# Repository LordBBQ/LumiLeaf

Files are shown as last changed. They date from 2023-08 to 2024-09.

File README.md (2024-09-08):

# LumiLeaf
Smart affordable adressable LED panels

### Assembly
##### Step 1

Remove the printed supports and adhesion materials from the part.

##### Step 2

Use a soldering iron to insert the 4 terminal heatset inserts.


Insert the M3 terminal bolts and washers into the inserts.

##### Step 3


Strip a length of solid core ethernet cable.


Separate the individual strands, and remove the twists as much as possible.

##### Step 4

Route the wires through the wire channel as shown.

##### Step 5

Cut a 250mm length of LED strip.



Adhere this around the edge of the light.

##### Step 6

Carefully solder the 4 wires to the 5V, GND, D+ and D- pins. This is very fiddly, and may require multiple attempts.

##### Step 7

Route the wires out the wire hole, and spread them to each of their terminals. 


Loop each wire around a bolt and tighten, ensuring there is no insulation clamped under the screw.

##### Step 8

Use a multimeter to check check for short circuts in the assembly.

##### Step 9

Cut out a triangular section of foil to act as the reflector.



Use a thin double sided tape to adhere the foil over the back panel.

>[!WARNING]
>Ensure the foil does not make contact with the LED strip or exposed wire. This could lead to a short circut!

##### Step 10
Repeat for all other desired modules. Attach the lasercut or 3D printed diffuser and bezel.

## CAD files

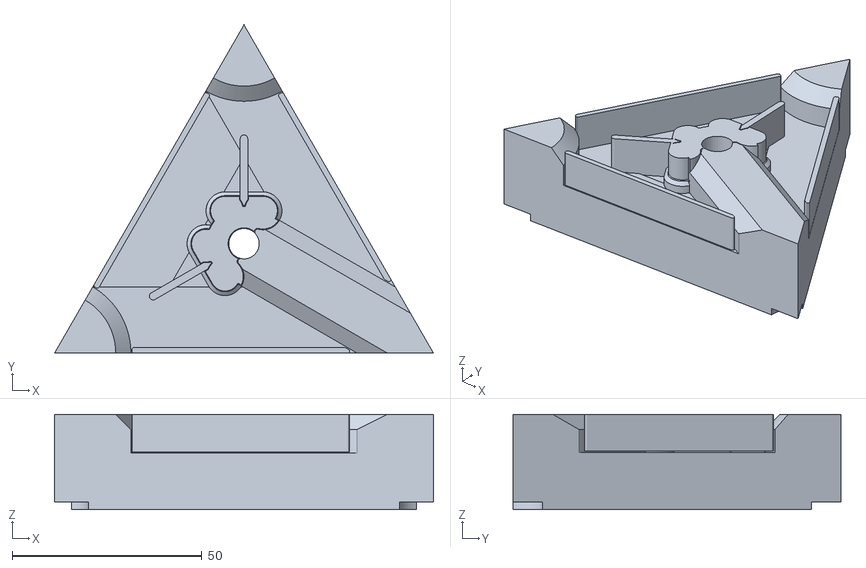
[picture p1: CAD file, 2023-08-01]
STLs/ElementBodyV2.stl
99.8 x 86.5 x 25.1

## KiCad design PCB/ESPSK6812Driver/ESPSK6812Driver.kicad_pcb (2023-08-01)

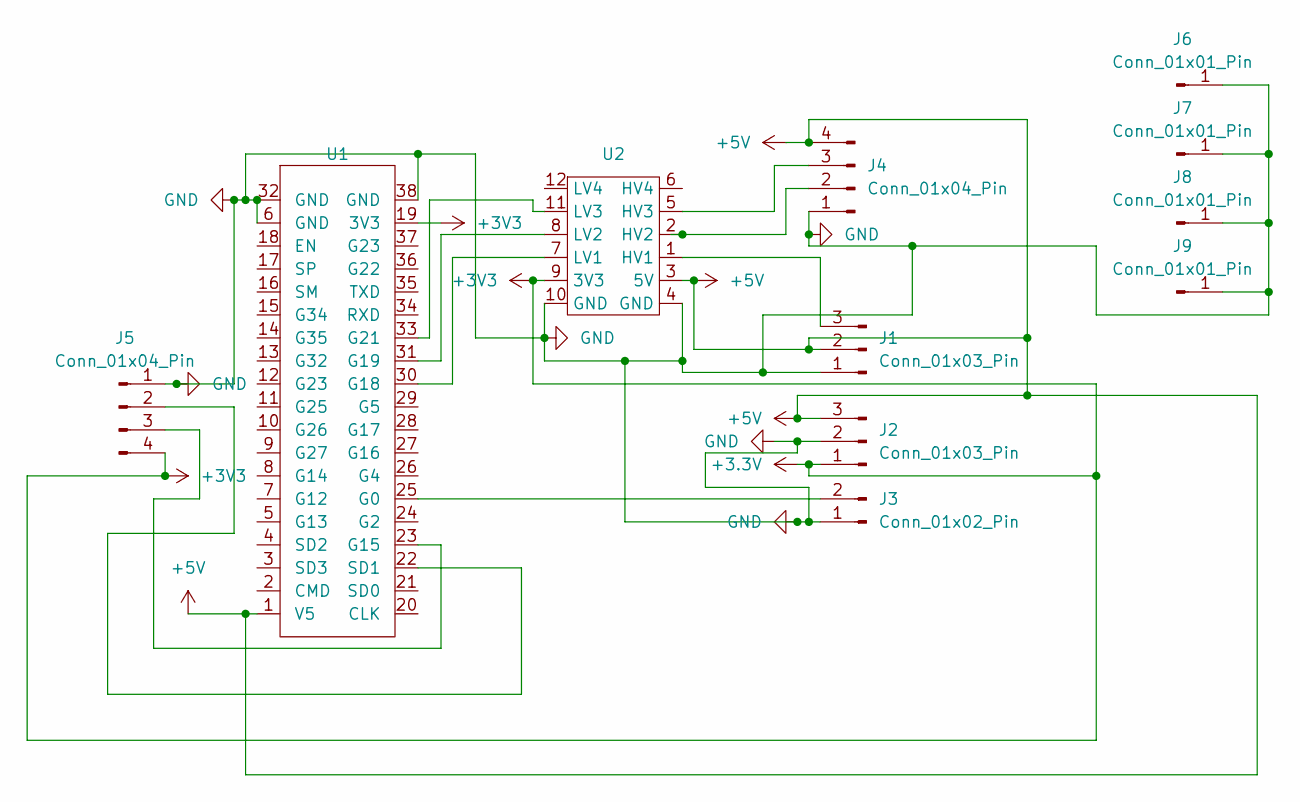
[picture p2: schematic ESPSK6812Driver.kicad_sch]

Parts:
J1, J2: Conn_01x03_Pin; JST_XH_B3B-XH-AM_1x03_P2.50mm_Vertical
J3: Conn_01x02_Pin; JST_XH_B2B-XH-AM_1x02_P2.50mm_Vertical
J4, J5: Conn_01x04_Pin; PinHeader_1x04_P2.54mm_Vertical
J6, J7, J8, J9: Conn_01x01_Pin; MountingHole_3.2mm_M3_DIN965_Pad
U1: ESPModuleJaycar
U2: LogicLevelShifterBidirectional

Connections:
+3.3V: J2.1, J5.4, U1.19 (3V3), U2.9 (3V3)
+5V: J1.2, J2.3, J4.4, U1.1 (V5), U2.3 (5V)
GND: J1.1, J2.2, J3.1, J4.1, J5.1, J6.1, J7.1, J8.1, J9.1, U1.6 (GND), U1.32 (GND), U1.38 (GND), U2.4 (GND), U2.10 (GND)
unnamed: J1.3, U2.1 (HV1)
unnamed: J3.2, U1.25 (G0)
unnamed: J4.2, U2.2 (HV2)
unnamed: J4.3, U2.5 (HV3)
unnamed: J5.2, U1.22 (SD1)
unnamed: J5.3, U1.23 (G15)
unnamed: U1.30 (G18), U2.7 (LV1)
unnamed: U1.31 (G19), U2.8 (LV2)
unnamed: U1.33 (G21), U2.11 (LV3)

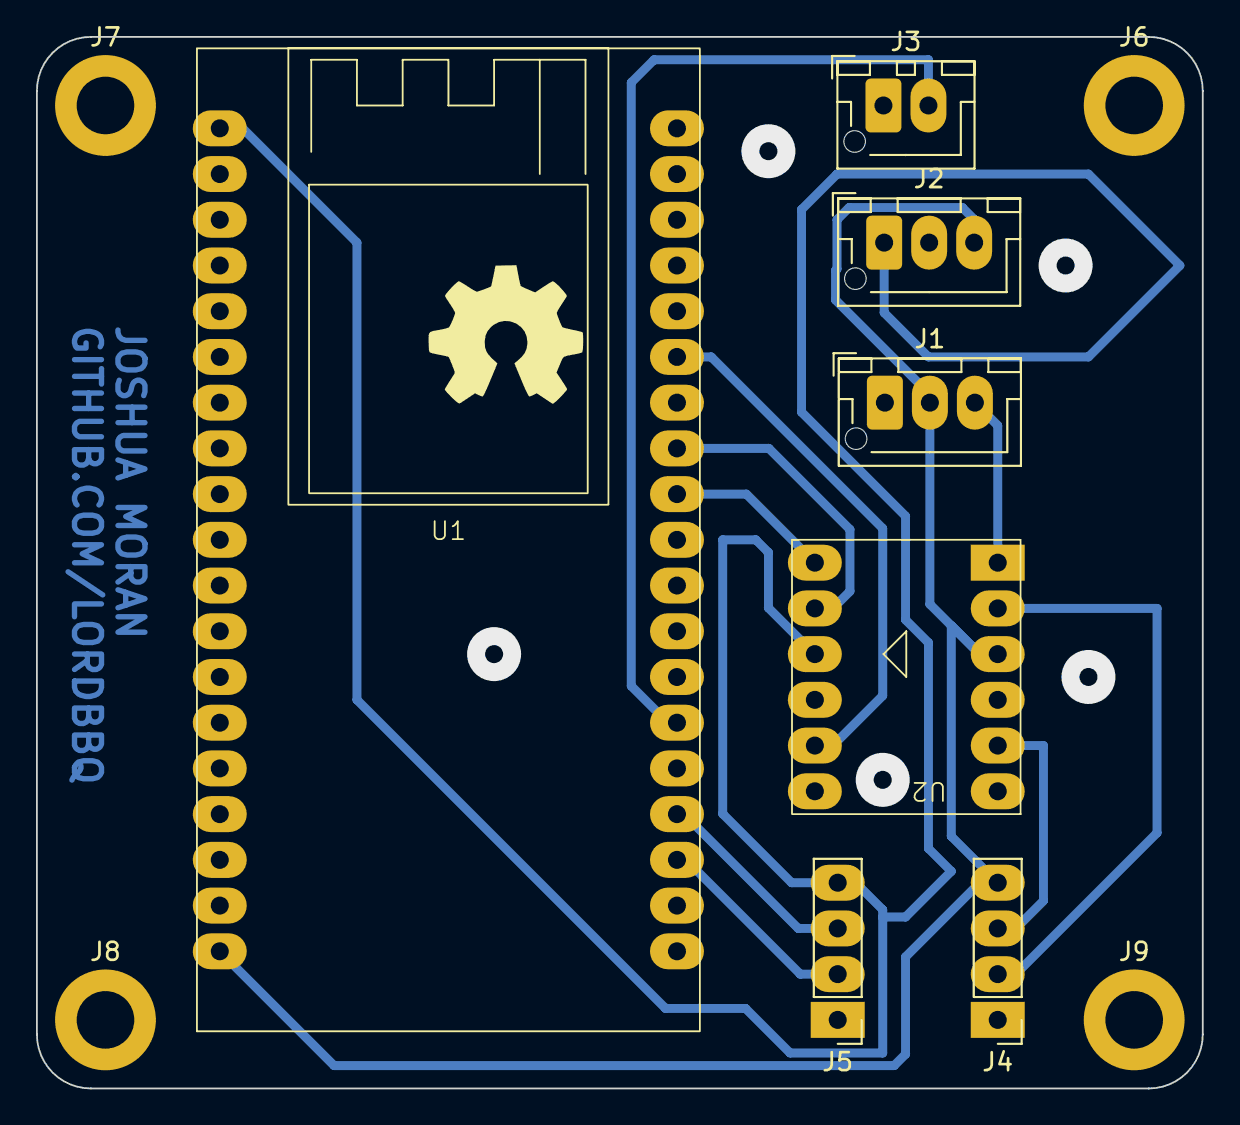
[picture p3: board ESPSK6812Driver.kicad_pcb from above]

Board: 2 copper layers, 64.8 x 58.4 mm, 11 parts (0 on the bottom side), 12 nets.
